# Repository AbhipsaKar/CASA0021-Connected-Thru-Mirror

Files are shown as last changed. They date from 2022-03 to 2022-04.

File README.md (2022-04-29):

# CASA0021-Connected-Thru-Mirror
Group project prototype created for CASA0021 module
<br>Product demo: https://www.youtube.com/watch?v=fjhPnnlj3zE

## What the project does
While getting ready to leave the house for the day, the user should be able to look at the mirror on the desk or wall in the hallway and get important information like the time of the next train or our work schedule for the day. The mirror displays the following information:
1. TFL bus timings at the nearest station
2. Weather/ forecast
3. Clock
4. Newsfeed  

The mirror is customised to the nearest station (currently it is set as King's Cross Station) and the calendar credentials while protecting the user's privacy from other guests using face recognition. Additionally, considering that a family would have multiple members, the mirror supports more than one profile. It has a timer that can countdouwn from 1,2,3,4 or 5 minutes and has a portal that allows recording and playing short videos.
The mirror is controlled by joystick and push button physically.

## Why the project is useful
The idea of having a mirror with display function stems from the limited living space in modern cities, as well as too many devices and screens with infrequent uses in terms of number and duration. Apart from design and decoration, the device serves as a tool to inform and assist users. There are smart mirrors available on the market or by DIY. However, they are mostly one-way which only show information to users and leave little room for users’ input. Often users can only read the information on the mirror, whether it be photos, texts, or videos, with little possibility to insert new information to the device. This product was designed with the ability to receive input data such as video,  as well as commands such as to control the information to be displayed, and set a stopwatch with adjustable length. Equipped with not only a screen but also sensors (camera), this device is an enhancement of the conventional smart mirror and enables bi-directional connection of user, device, and different data sources.
Potential users for this device include technophiles as well as potentially anyone at home, office, or hotel, acquiring the device either by themselves or by the property developers/company. In addition, this product has potential to connect relatives living away through short video messages.

Storyboard

## How to get started
### Components
1.	Raspberry Pi (we used Raspberry Pi 4 Model B)
2.	Screen
3.	Two way mirror
4.	Arcade Joystick
5.	Illuminated Push Button Switch (or any push button)
6.	4 10K Resistors
7.	Jumper wires
8.	Breadboard
9.	3D printed enclosure
Depends on what push button is used:
10.	Solid Wires 
11.	Solder station

### Modules
1. MMM-Buttons https://github.com/Jopyth/MMM-Buttons
2. MMM-Carousel2 https://github.com/lpage30/MMM-Carousel2
3. MMM-Facial-Recognition https://github.com/paviro/MMM-Facial-Recognition
4. MMM-ProfileSwitcher https://github.com/tosti007/MMM-ProfileSwitcher
5. MMM-TFL-Arrivals https://github.com/ryck/MMM-TFL-Arrivals
6. MMM-ModifiedTimer
7. MMM-RecordPortal
8. MMM-PlayPortal

### Installation :
You can recreate this mirror on your own Rpi using the following steps:
1.	Install MagicMirror2 on Raspberry Pi(use tutorial: https://howchoo.com/g/ntcymzbimjv/how-to-install-magic-mirror-on-your-raspberry-pi)
2.	Enable VNC, Camera and GPIO in the rpi configuration menu($ sudo raspi-config)
3.	run following command in home folder to install mqtt: 
$ cd MagicMirror 
$ npm install mqtt
4.	Replace the config, css and modules folder in the MagicMirror folder from this repository.
5.	Unzip the node_modules file in MMM-Buttons, MMM-Carousel2, MMM-TFL-Arrivals-Modified
6.	Edit the config.js file in the config folder
    - The naptanID for the MMM-TFL-Arrivals-Modified module can be found in the URLs of the bus stop webpage on TFL
      e.g. King's Cross Station has a naptanID of 490000129E and can be found within https://tfl.gov.uk/bus/stop/490000129E/kings-cross-station
    - The locationID for the weather and weatherforcast modules can be found in http://bulk.openweathermap.org/sample/city.list.json.gz or within the URLs of the openweathermap websites
      e.g. London, GB has a location ID of 2643743 and can be found within https://openweathermap.org/city/2643743
    - The apiKey and appid for the weather and weatherforcast modules are the API KEY from your openweathermap account
    - Add your desired calendar url for calendar module
7.  Add the MQTT url, username and password in ~/MagicMirror/modules/MMM-RecordPlayer/node_helper.js
6.	Connect the joystick and push button according to the Fritzing diagram below


### Start magic mirror
1. Download the testbutton.py
2. Run testbutton.py
```
cd Documents
python testbutton.py
```
3. Move the joystick and press the push button so that the console prints the detected actions
4. If the printed messages are correct, start MagicMirror
```
cd ~/MagicMirror
npm start
```

## Where to get help
For MagicMirror2 related questions, please refer to the official documentations or MagicMirror Forum https://forum.magicmirror.builders/

## Challenges
1. Since there is only one hardware setup, it is difficult for us to work individually or test the codes.
2. AI module cannot work in tandem with the portal module due to camera resource deadlock. Therefore we restricted the AI to work only during initialization. To change the profile, the mirror has to be restarted.
3. In the AI module, sometimes an unknown face was also recognised as a known face with a quite low score, therefore a threshold was set to filter the low score faces.
4. For unknown reason, sometimes the button and joystick do not work. To solve this, a script called testbutton.py was written. After running this script, the button and joystick would work again.
5. In the portal mode development, it was extremely difficult to publish the video on MQTT due to the asynchronous nature of Javascript and memory intensive nature of blob video chunks. This issue was overcome using correct scoping of variables and using promises.
6. The portal modules were always playing in the background. To fix this, suspend and resume functions were added to restrict them to their corresponding pages.

## Future improvements
1.The purchased mirror performs well in being reflective, yet its transparency is suboptimal especially in a bright environment. A high quality mirror and spare parts would enhance visibility and flexibility. 
2.The current setup only works on a desk and take up a lot of spaces, more compacted components can be purchased so that the mirror can be thin enough to be placed anywhere.
3.A public MQTT is used due to operational constraints. In the future, a private MQTT should be used and the videos should be transmitted in an encrypted format.
In fact, although MQTT works for short videos, an FTP server should be used for storing videos. MQTT should be used for conveying the notifications and ftp url.
4.Currently, all videos sent by the sender mirror can be viewed by everyone on the receiving mirror. In the future iterations, technical specifications should allow one profile to communicate with another profile on a separate mirror. 
5.The future product would likely be accompanied with an app which would enable users to set up the magic mirror with the nearest station, training the AI module, add a new profile and set a calendar. Users can also choose to add/remove modules or change ownership easily without delving into the code. Bu supporting login/logout facility these mirrors can be used in a public setting like hotels.

## Contributors
AbhipsaKar https://github.com/AbhipsaKar
abichoi https://github.com/abichoi
WingHongCASACE https://github.com/WingHongCASACE
Zixu Cheng https://github.com/Cheng-Zixu

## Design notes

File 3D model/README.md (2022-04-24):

This folder contains stl files of the 3D printed components

<p align='center'>

</p>

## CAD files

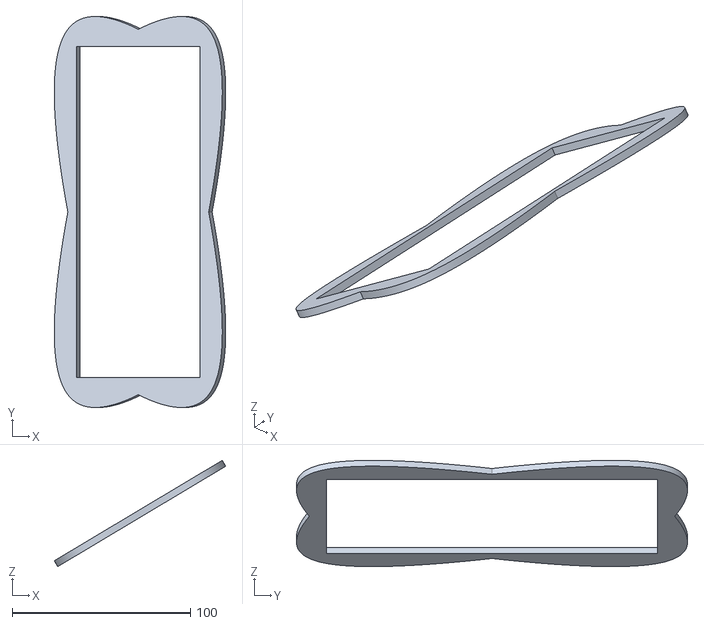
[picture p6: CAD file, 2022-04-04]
3D model/locking frame.stl
96.2 x 219.4 x 59.6

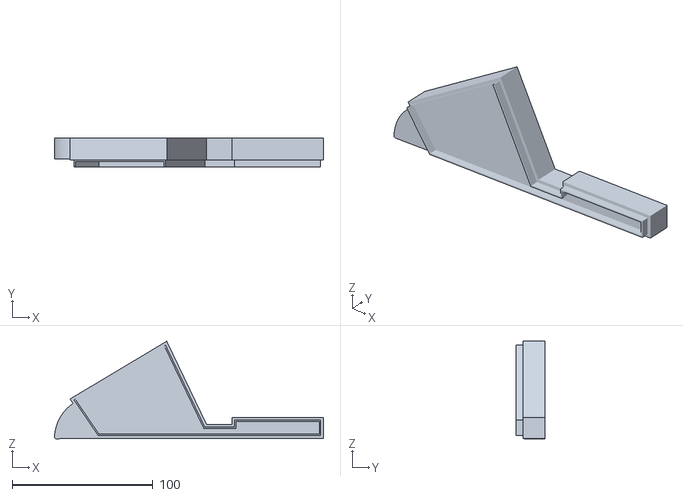
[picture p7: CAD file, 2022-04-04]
3D model/lid.stl
190.9 x 20.8 x 69.2

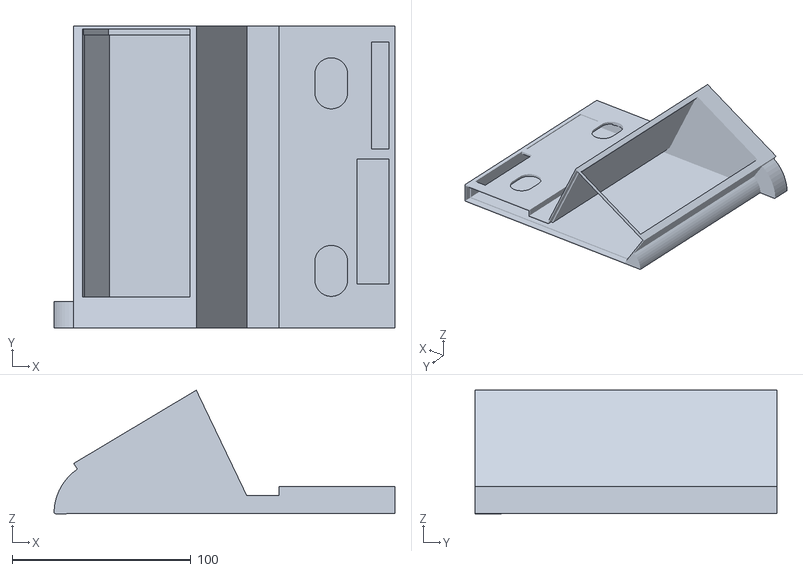
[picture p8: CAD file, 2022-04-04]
3D model/case body.stl
190.9 x 169.2 x 69.2

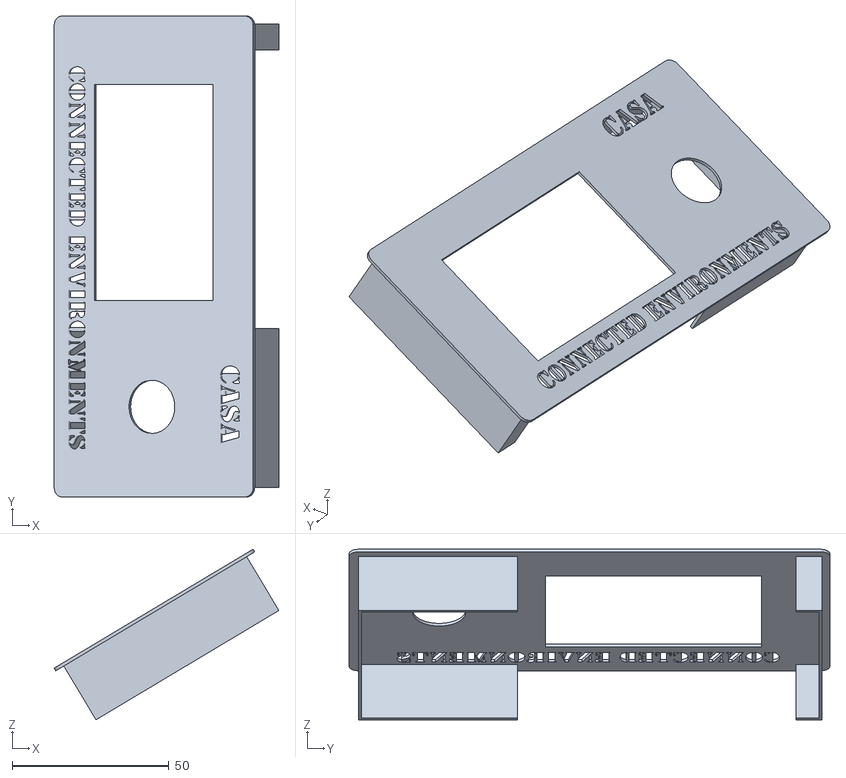
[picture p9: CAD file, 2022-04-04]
3D model/panel.stl
71.7 x 153.5 x 54.5

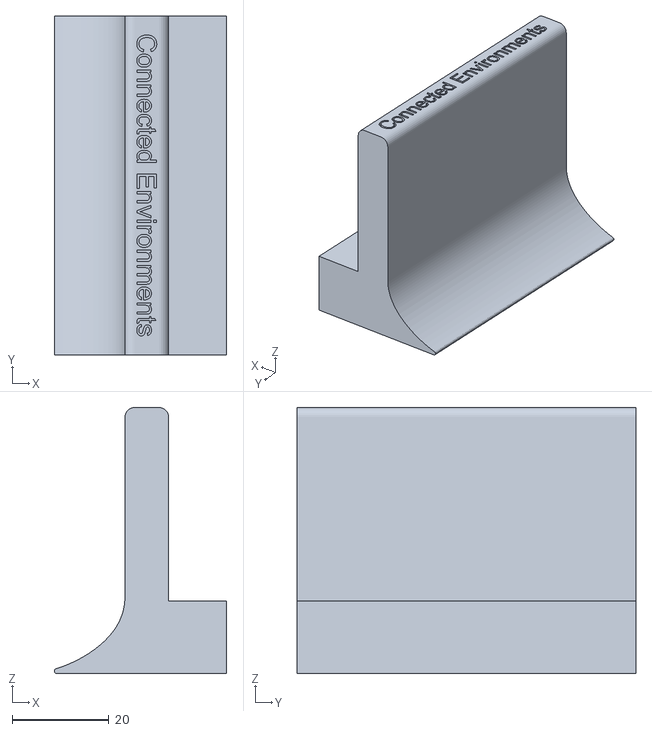
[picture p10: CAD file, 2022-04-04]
3D model/screen support.stl
35.7 x 70.0 x 55.0

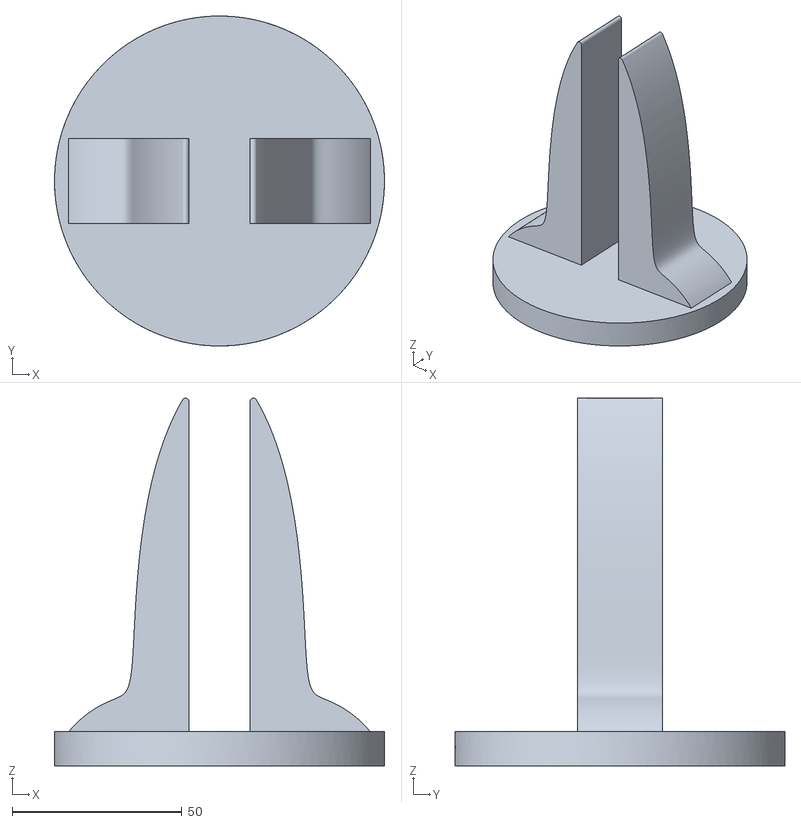
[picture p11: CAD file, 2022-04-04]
3D model/frame stand.stl
97.1 x 97.1 x 108.3

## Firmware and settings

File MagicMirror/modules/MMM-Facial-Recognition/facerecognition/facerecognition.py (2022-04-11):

#!/usr/bin/python
# coding: utf8
"""MMM-Facial-Recognition - MagicMirror Module
Face Recognition Script
The MIT License (MIT)

Copyright (c) 2016 Paul-Vincent Roll (MIT License)
Based on work by Tony DiCola (Copyright 2013) (MIT License)

Permission is hereby granted, free of charge, to any person obtaining a copy of this software and associated documentation files (the "Software"), to deal in the Software without restriction, including without limitation the rights to use, copy, modify, merge, publish, distribute, sublicense, and/or sell copies of the Software, and to permit persons to whom the Software is furnished to do so, subject to the following conditions:

The above copyright notice and this permission notice shall be included in all copies or substantial portions of the Software.

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
import sys
import json
import time
import face
import cv2
import config
import signal

from aip import AipFace
import base64
import numpy as np
#from picamera import PiCamera
import urllib.request
#import RPi.GPIO as GPIO


""" My APPID AK SK """
APP_ID = 'XXX'
API_KEY = 'XXXX'
SECRET_KEY = 'XXXX'

client = AipFace(APP_ID, API_KEY, SECRET_KEY)
#camera = PiCamera()
IMAGE_TYPE = "BASE64"
GROUP = "1"


def image_to_base64(image_np):
    image = cv2.imencode('faceimage.jpg',image_np)[1]
    image_code = str(base64.b64encode(image))[2:-1]
    return image_code

def face_recognition_api(image):
    result = client.search(image, IMAGE_TYPE, GROUP)
    uid = ""
    score = 0.0
    # print(result)
    
    if result['error_msg'] == 'SUCCESS':
        uid = result['result']['user_list'][0]['user_id']
        score = result['result']['user_list'][0]['score']
    to_node("status", "uid: " + str(uid) + " score: " + str(score))
    return uid, score



def to_node(type, message):
    # convert to json and print (node helper will read from stdout)
    try:
        print(json.dumps({type: message}))
    except Exception:
        pass
    # stdout has to be flushed manually to prevent delays in the node helper communication
    sys.stdout.flush()


to_node("status", "Facerecognition started...")

# Setup variables
current_user = None
last_match = None
detection_active = True
looping = True
login_timestamp = time.time()
same_user_detected_in_row = 0
loop_count = 0

# Load training data into model
to_node("status", 'Loading training data...')

# set algorithm to be used based on setting in config.js
if config.get("recognitionAlgorithm") == 1:
    to_node("status", "ALGORITHM: LBPH")
    model = cv2.face.LBPHFaceRecognizer_create(threshold=config.get("lbphThreshold"))
elif config.get("recognitionAlgorithm") == 2:
    to_node("status", "ALGORITHM: Fisher")
    model = cv2.face.FisherFaceRecognizer_create(threshold=config.get("fisherThreshold"))
else:
    to_node("status", "ALGORITHM: Eigen")
    model = cv2.face.EigenFaceRecognizer_create(threshold=config.get("eigenThreshold"))

# Load training file specified in config.js
model.read(config.get("trainingFile"))
to_node("status", 'Training data loaded!')

# get camera
camera = config.get_camera()
to_node("status", 'camera loaded!')

def shutdown(self, signum):
    to_node("status", 'Shutdown: Cleaning up camera...')
    camera.stop()
    quit()

signal.signal(signal.SIGINT, shutdown)
# sleep for a second to let the camera warm up
time.sleep(1)

# Main Loop
while looping:
    # Sleep for x seconds specified in module config
    time.sleep(config.get("interval"))
    # if detecion is true, will be used to disable detection if you use a PIR sensor and no motion is detected
    if detection_active is True:
        # Get image
        loop_count = loop_count + 1
        if loop_count > 3:
            looping = False
        image = camera.read()
        to_node("status", "camera read...")
        # Convert image to grayscale.
        #image = cv2.cvtColor(image, cv2.COLOR_RGB2GRAY)
        image = image_to_base64(image)
        label, confidence = face_recognition_api(image)
        to_node("status", "get face recognition result")
        # Get coordinates of single face in captured image.
        # result = face.detect_single(image)
        # # No face found, logout user?
        # if result is None:
        #     # if last detection exceeds timeout and there is someone logged in -> logout!
        #     if (current_user is not None and time.time() - login_timestamp > config.get("logoutDelay")):
        #         # callback logout to node helper
        #         to_node("logout", {"user": current_user})
        #         same_user_detected_in_row = 0
        #         current_user = None
        #     continue
        # # Set x,y coordinates, height and width from face detection result
        # x, y, w, h = result
        # # Crop image on face. If algorithm is not LBPH also resize because in all other algorithms image resolution has to be the same as training image resolution.
        # if config.get("recognitionAlgorithm") == 1:
        #     crop = face.crop(image, x, y, w, h)
        # else:
        #     crop = face.resize(face.crop(image, x, y, w, h))
        # # Test face against model.
        # label, confidence = model.predict(crop)
        # We have a match if the label is not "-1" which equals unknown because of exceeded threshold and is not "0" which are negtive training images (see training folder).
        if (label != -1 and label != 0):
            # Set login time
            login_timestamp = time.time()
            # Routine to count how many times the same user is detected
            if (label == last_match and same_user_detected_in_row < 2):
                # if same user as last time increment same_user_detected_in_row +1
                same_user_detected_in_row += 1
            if label != last_match:
                # if the user is diffrent reset same_user_detected_in_row back to 0
                same_user_detected_in_row = 0
            # A user only gets logged in if he is predicted twice in a row minimizing prediction errors.
            if (label != current_user and same_user_detected_in_row > 0):
                current_user = label
                # Callback current user to node helper
                to_node("login", {"user": label, "confidence": str(confidence)})
            # set last_match to current prediction
            last_match = label
        # if label is -1 or 0, current_user is not already set to unknown and last prediction match was at least 5 seconds ago
        # (to prevent unknown detection of a known user if he moves for example and can't be detected correctly)
        elif (current_user != 0 and time.time() - login_timestamp > 5):
            # Set login time
            login_timestamp = time.time()
            # set current_user to unknown
            current_user = 0
            # callback to node helper
            to_node("login", {"user": current_user, "confidence": None})
        else:
            continue
        

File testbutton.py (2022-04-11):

import RPi.GPIO as GPIO
import time

GPIO.setmode(GPIO.BCM)
GPIO.setup(15, GPIO.IN, pull_up_down = GPIO.PUD_DOWN)
GPIO.setup(26, GPIO.IN, pull_up_down = GPIO.PUD_DOWN)
GPIO.setup(10, GPIO.IN, pull_up_down = GPIO.PUD_UP)
GPIO.setup(17, GPIO.IN, pull_up_down = GPIO.PUD_UP)
GPIO.setup(16, GPIO.IN, pull_up_down = GPIO.PUD_UP)
GPIO.setup(9, GPIO.IN, pull_up_down = GPIO.PUD_UP)

tries = 0

while(tries < 200):
	if GPIO.input(15):
		print("Regular Button Pressed")
	elif GPIO.input(10) == GPIO.LOW:
		print("Joystick up")
	elif GPIO.input(17)== GPIO.LOW:
		print("Joystick down")
	elif GPIO.input(16)== GPIO.LOW:
		print("Joystick left")
	elif GPIO.input(9)== GPIO.LOW:
		print("Joystick right")
	elif GPIO.input(26):
		print("Light Push Button Pressed")	
	else:
		print("No button")
	time.sleep(0.5)
	tries = tries + 1

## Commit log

2022-04-08 updated button color
2022-04-11 A script used to test the buttons that was used in the project.
